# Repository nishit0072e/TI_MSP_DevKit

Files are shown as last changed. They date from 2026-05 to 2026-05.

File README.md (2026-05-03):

### 3D View
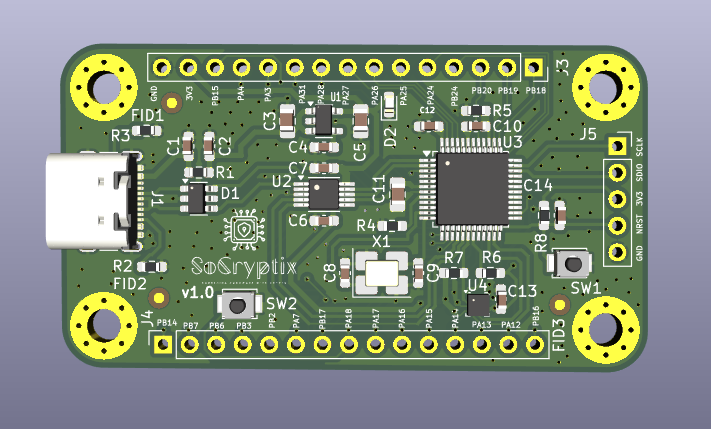
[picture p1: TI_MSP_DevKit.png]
3D View

### Schematic View
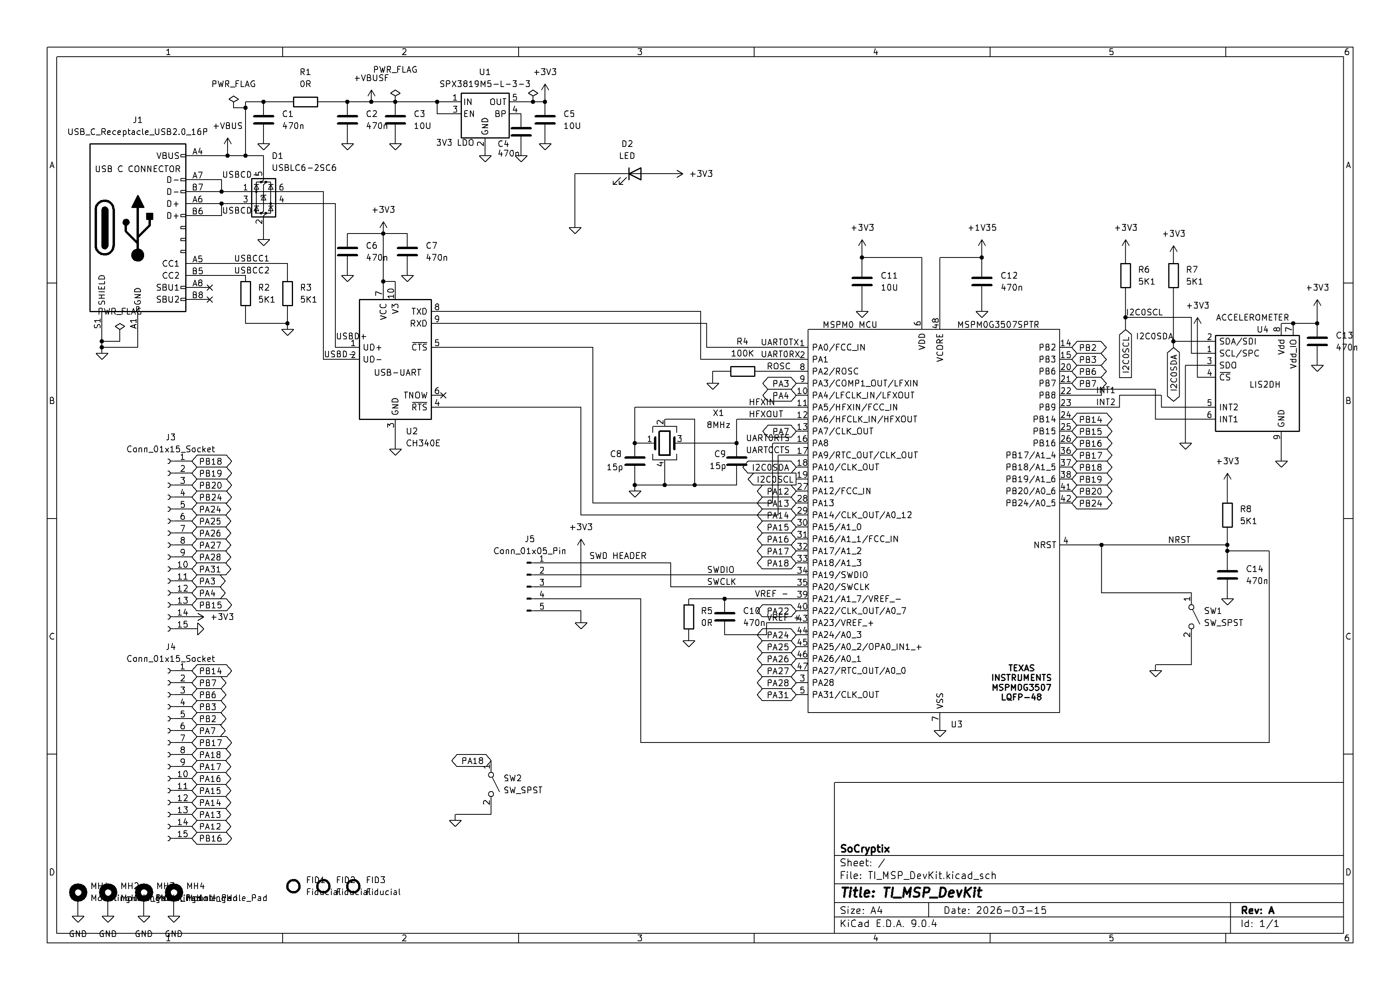
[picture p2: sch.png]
Schematic

### Front Copper
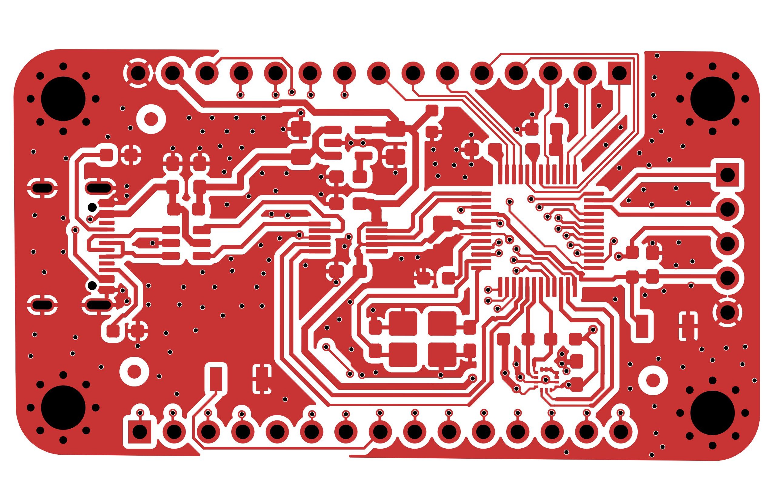
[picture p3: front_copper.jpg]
Front_copper

### Rear Copper
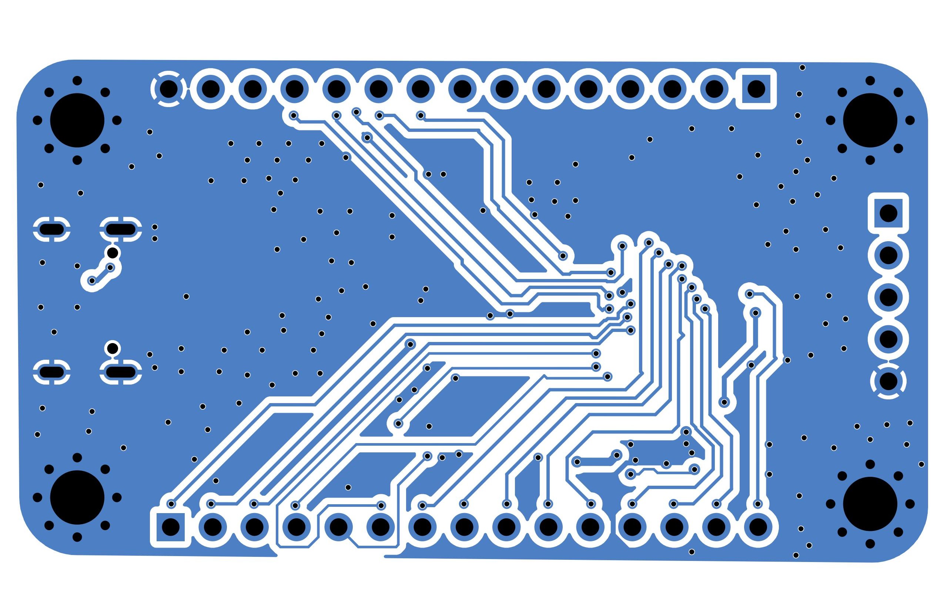
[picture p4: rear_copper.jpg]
Read_copper

### SilkScreen
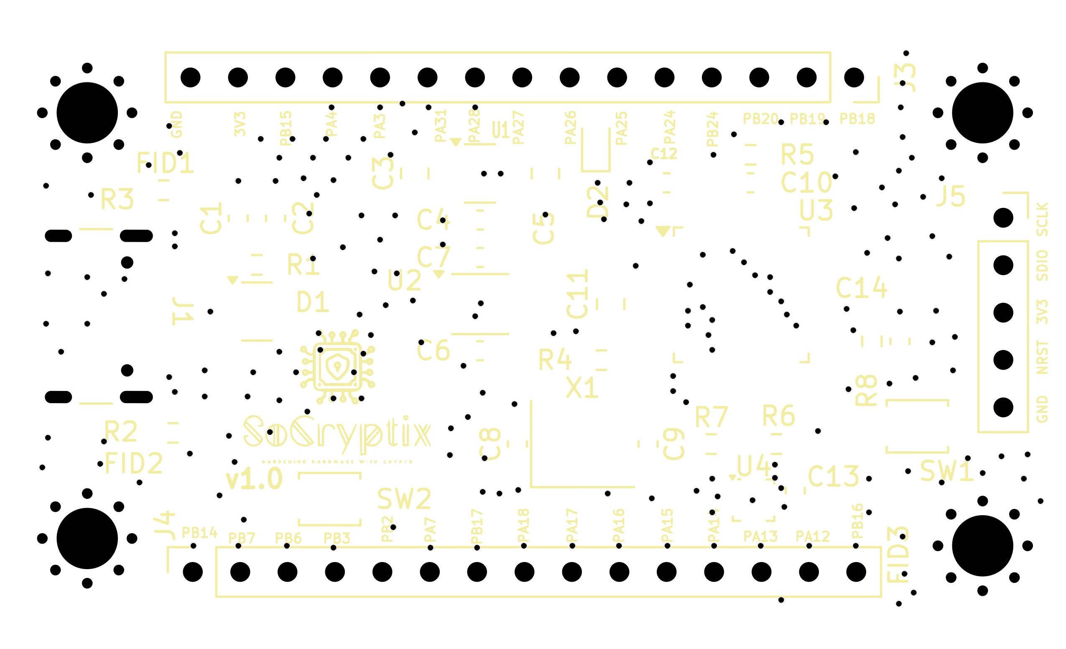
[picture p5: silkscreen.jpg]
Silkscreen

### Solder Mask
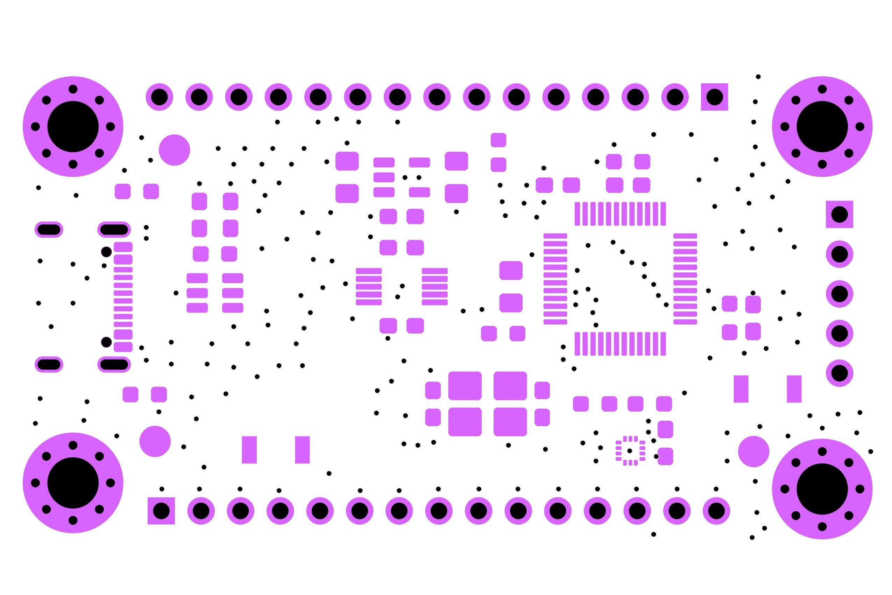
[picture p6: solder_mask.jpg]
Solder_Mask


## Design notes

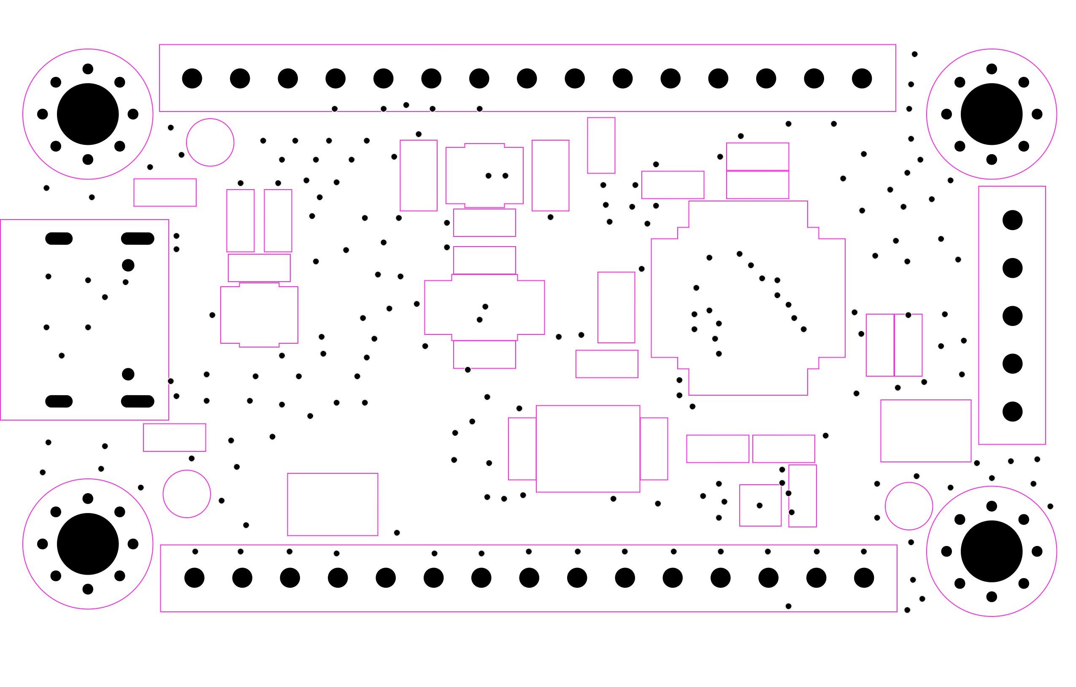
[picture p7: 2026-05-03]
front_courtyard.jpg

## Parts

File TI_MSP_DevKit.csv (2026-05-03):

Reference | Qty | Value | DNP | Exclude from BOM | Exclude from Board | Footprint | Datasheet | LCSC
C1,C2,C4,C6,C7,C10,C12,C13,C14 | 9 | 470n |  |  |  | Capacitor_SMD:C_0603_1608Metric_Pad1.08x0.95mm_HandSolder | ~ | C13967
C3,C5,C11 | 3 | 10U |  |  |  | Capacitor_SMD:C_0805_2012Metric_Pad1.18x1.45mm_HandSolder | ~ | C15850
C8,C9 | 2 | 15p |  |  |  | Capacitor_SMD:C_0603_1608Metric_Pad1.08x0.95mm_HandSolder | ~ | C2594277
D1 | 1 | USBLC6-2SC6 |  |  |  | Package_TO_SOT_SMD:SOT-23-6 | https://www.st.com/resource/en/datasheet/usblc6-2.pdf | C2827654
D2 | 1 | LED |  |  |  | LED_SMD:LED_0603_1608Metric | ~ | C19171390
FID1,FID2,FID3 | 3 | Fiducial |  | Excluded from BOM |  | Fiducial:Fiducial_1mm_Mask2mm | ~
J1 | 1 | USB_C_Receptacle_USB2.0_16P |  |  |  | Connector_USB:USB_C_Receptacle_GCT_USB4105-xx-A_16P_TopMnt_Horizontal | https://www.usb.org/sites/default/files/documents/usb_type-c.zip | C2765186
J3,J4 | 2 | Conn_01x15_Socket |  |  |  | Connector_PinSocket_2.54mm:PinSocket_1x15_P2.54mm_Vertical | ~ | C7499333
J5 | 1 | Conn_01x05_Pin |  |  |  | Connector_PinSocket_2.54mm:PinSocket_1x05_P2.54mm_Vertical | ~ | C42431835
MH1,MH2,MH3,MH4 | 4 | MountingHole_Pad |  | Excluded from BOM |  | MountingHole:MountingHole_3.2mm_M3_Pad_Via | ~
R1,R5 | 2 | 0R |  |  |  | Resistor_SMD:R_0603_1608Metric_Pad0.98x0.95mm_HandSolder | ~ | C95177
R2,R3,R6,R7,R8 | 5 | 5K1 |  |  |  | Resistor_SMD:R_0603_1608Metric_Pad0.98x0.95mm_HandSolder | ~ | C2907044
R4 | 1 | 100K |  |  |  | Resistor_SMD:R_0603_1608Metric_Pad0.98x0.95mm_HandSolder | ~ | C122538
SW1,SW2 | 2 | SW_SPST |  |  |  | Button_Switch_SMD:SW_SPST_B3U-1000P | ~ | C720477
U1 | 1 | SPX3819M5-L-3-3 |  |  |  | Package_TO_SOT_SMD:SOT-23-5 | https://www.exar.com/content/document.ashx?id=22106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 | C9055
U2 | 1 | CH340E |  |  |  | Package_SO:MSOP-10_3x3mm_P0.5mm | https://www.mpja.com/download/35227cpdata.pdf | C99652
U3 | 1 | MSPM0G3507SPTR |  |  |  | Package_QFP:LQFP-48_7x7mm_P0.5mm | https://www.ti.com/lit/ds/symlink/mspm0g3507.pdf?ts=1773558363695 | C22362630
U4 | 1 | LIS2DH |  |  |  | Package_LGA:LGA-14_2x2mm_P0.35mm_LayoutBorder3x4y | http://www.st.com/web/en/resource/technical/document/datasheet/DM00042751.pdf | C110926
X1 | 1 | 8MHz |  |  |  | Crystal:Crystal_SMD_3225-4Pin_3.2x2.5mm_HandSoldering | ~ | C390495

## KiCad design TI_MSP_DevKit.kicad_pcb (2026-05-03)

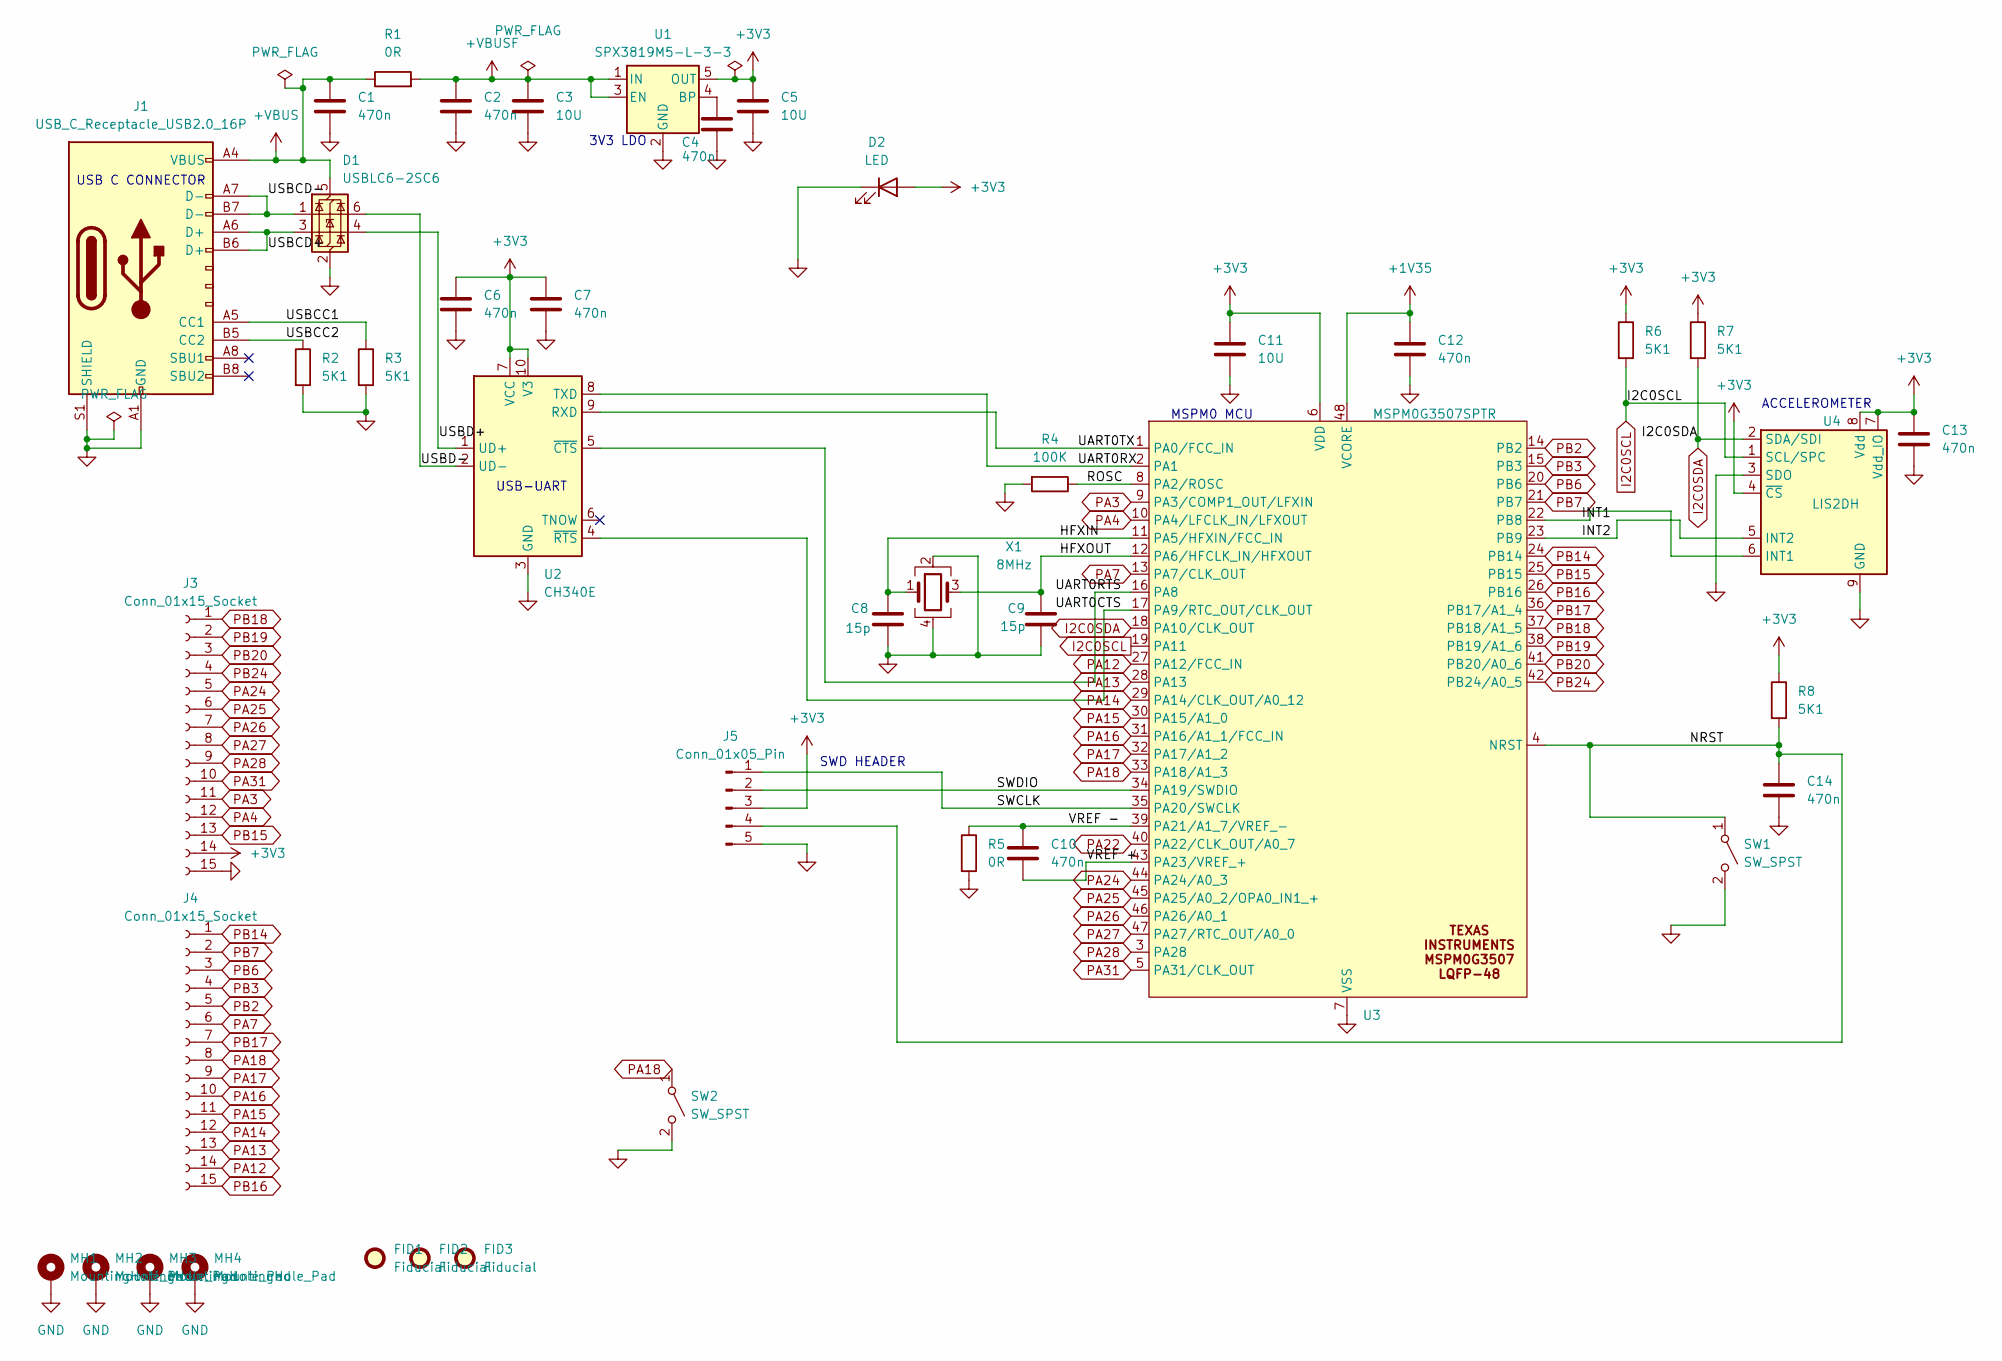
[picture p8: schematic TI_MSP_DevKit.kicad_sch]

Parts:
C1, C2, C4, C6, C7, C10, C12, C13, C14: 470n; C_0603_1608Metric_Pad1.08x0.95mm_HandSolder; Part Number CL21B474KBFNNNE; LCSC C13967
C3, C5, C11: 10U; C_0805_2012Metric_Pad1.18x1.45mm_HandSolder; Part Number CL21A106KAYNNNE; LCSC C15850
C8, C9: 15p; C_0603_1608Metric_Pad1.08x0.95mm_HandSolder; Part Number CL21B474KBFNNNE; LCSC C2594277
D1: USBLC6-2SC6; SOT-23-6; LCSC C2827654
D2: LED; LED_0603_1608Metric; LCSC C19171390
FID1, FID2, FID3: Fiducial; Fiducial_1mm_Mask2mm
J1: USB_C_Receptacle_USB2.0_16P; USB_C_Receptacle_GCT_USB4105-xx-A_16P_TopMnt_Horizontal; LCSC C2765186
J3, J4: Conn_01x15_Socket; PinSocket_1x15_P2.54mm_Vertical; LCSC C7499333
J5: Conn_01x05_Pin; PinSocket_1x05_P2.54mm_Vertical; LCSC C42431835
MH1, MH2, MH3, MH4: MountingHole_Pad; MountingHole_3.2mm_M3_Pad_Via
R1, R5: 0R; R_0603_1608Metric_Pad0.98x0.95mm_HandSolder; LCSC C95177
R2, R3, R6, R7, R8: 5K1; R_0603_1608Metric_Pad0.98x0.95mm_HandSolder; LCSC C2907044
R4: 100K; R_0603_1608Metric_Pad0.98x0.95mm_HandSolder; Part Number RT0603BRD07100KL; LCSC C122538
SW1, SW2: SW_SPST; SW_SPST_B3U-1000P; LCSC C720477
U1: SPX3819M5-L-3-3; SOT-23-5; LCSC C9055
U2: CH340E; MSOP-10_3x3mm_P0.5mm; LCSC C99652
U3: MSPM0G3507SPTR; LQFP-48_7x7mm_P0.5mm; Manufacturer Part Number MSPM0G3507SPTR; LCSC C22362630
U4: LIS2DH; LGA-14_2x2mm_P0.35mm_LayoutBorder3x4y; LCSC C110926
X1: 8MHz; Crystal_SMD_3225-4Pin_3.2x2.5mm_HandSoldering; LCSC C390495

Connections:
+1V35: C12.1, U3.48 (VCORE)
+3V3: C5.1, C6.1, C7.1, C11.1, C13.1, D2.2 (A), J3.14, J5.3, R6.1, R7.1, R8.1, U1.5 (OUT), U2.7 (VCC), U2.10 (V3), U3.6 (VDD), U4.4 (~CS), U4.7 (Vdd_IO), U4.8 (Vdd)
+VBUS: C1.1, D1.5 (VBUS), J1.A4 (VBUS), J1.A9 (VBUS), J1.B4 (VBUS), J1.B9 (VBUS), R1.1
+VBUSF: C2.1, C3.1, R1.2, U1.1 (IN), U1.3 (EN)
/HFXIN: C8.1, U3.11 (PA5/HFXIN/FCC_IN), X1.1
/HFXOUT: C9.1, U3.12 (PA6/HFCLK_IN/HFXOUT), X1.3
/INT1: U3.22 (PB8), U4.6 (INT1)
/INT2: U3.23 (PB9), U4.5 (INT2)
/NRST: C14.1, J5.4, R8.2, SW1.1 (A), U3.4 (NRST)
/ROSC: R4.1, U3.8 (PA2/ROSC)
/SWCLK: J5.1, U3.35 (PA20/SWCLK)
/SWDIO: J5.2, U3.34 (PA19/SWDIO)
/UART0CTS: U2.4 (~RTS), U3.17 (PA9/RTC_OUT/CLK_OUT)
/UART0RTS: U2.5 (~CTS), U3.16 (PA8)
/UART0RX: U2.8 (TXD), U3.2 (PA1)
/UART0TX: U2.9 (RXD), U3.1 (PA0/FCC_IN)
/USBCC1: J1.A5 (CC1), R3.1
/USBCC2: J1.B5 (CC2), R2.1
/USBCD+: D1.3 (I/O2), J1.A6 (D+), J1.B6 (D+)
/USBCD-: D1.1 (I/O1), J1.A7 (D-), J1.B7 (D-)
/USBD+: D1.4 (I/O2), U2.1 (UD+)
/USBD-: D1.6 (I/O1), U2.2 (UD-)
/VREF +: C10.2, U3.43 (PA23/VREF_+)
/VREF -: C10.1, R5.1, U3.39 (PA21/A1_7/VREF_-)
GND: C1.2, C2.2, C3.2, C4.2, C5.2, C6.2, C7.2, C8.2, C9.2, C11.2, C12.2, C13.2, C14.2, D1.2 (GND), D2.1 (K), J1.A1 (GND), J1.A12 (GND), J1.B1 (GND), J1.B12 (GND), J1.S1 (SHIELD), J3.15, J5.5, MH1.1, MH2.1, MH3.1, MH4.1, R2.2, R3.2, R4.2, R5.2, SW1.2 (B), SW2.2 (B), U1.2 (GND), U2.3 (GND), U3.7 (VSS), U4.3 (SDO), U4.9 (GND), X1.2, X1.4
I2C0SCL: R6.2, U3.19 (PA11), U4.1 (SCL/SPC)
I2C0SDA: R7.2, U3.18 (PA10/CLK_OUT), U4.2 (SDA/SDI)
unnamed: C4.1, U1.4 (BP)
unnamed: U4.10 (GND), U4.11 (GND), U4.12 (GND), U4.13 (GND), U4.14 (GND)
PA3: J3.11, U3.9 (PA3/COMP1_OUT/LFXIN)
PA4: J3.12, U3.10 (PA4/LFCLK_IN/LFXOUT)
PA7: J4.6, U3.13 (PA7/CLK_OUT)
PA12: J4.14, U3.27 (PA12/FCC_IN)
PA13: J4.13, U3.28 (PA13)
PA14: J4.12, U3.29 (PA14/CLK_OUT/A0_12)
PA15: J4.11, U3.30 (PA15/A1_0)
PA16: J4.10, U3.31 (PA16/A1_1/FCC_IN)
PA17: J4.9, U3.32 (PA17/A1_2)
PA18: J4.8, SW2.1 (A), U3.33 (PA18/A1_3)
PA22: U3.40 (PA22/CLK_OUT/A0_7)
PA24: J3.5, U3.44 (PA24/A0_3)
PA25: J3.6, U3.45 (PA25/A0_2/OPA0_IN1_+)
PA26: J3.7, U3.46 (PA26/A0_1)
PA27: J3.8, U3.47 (PA27/RTC_OUT/A0_0)
PA28: J3.9, U3.3 (PA28)
PA31: J3.10, U3.5 (PA31/CLK_OUT)
PB2: J4.5, U3.14 (PB2)
PB3: J4.4, U3.15 (PB3)
PB6: J4.3, U3.20 (PB6)
PB7: J4.2, U3.21 (PB7)
PB14: J4.1, U3.24 (PB14)
PB15: J3.13, U3.25 (PB15)
PB16: J4.15, U3.26 (PB16)
PB17: J4.7, U3.36 (PB17/A1_4)
PB18: J3.1, U3.37 (PB18/A1_5)
PB19: J3.2, U3.38 (PB19/A1_6)
PB20: J3.3, U3.41 (PB20/A0_6)
PB24: J3.4, U3.42 (PB24/A0_5)

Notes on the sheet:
MSPM0 MCU
ACCELEROMETER
USB-UART
SWD HEADER
USB C CONNECTOR
3V3 LDO

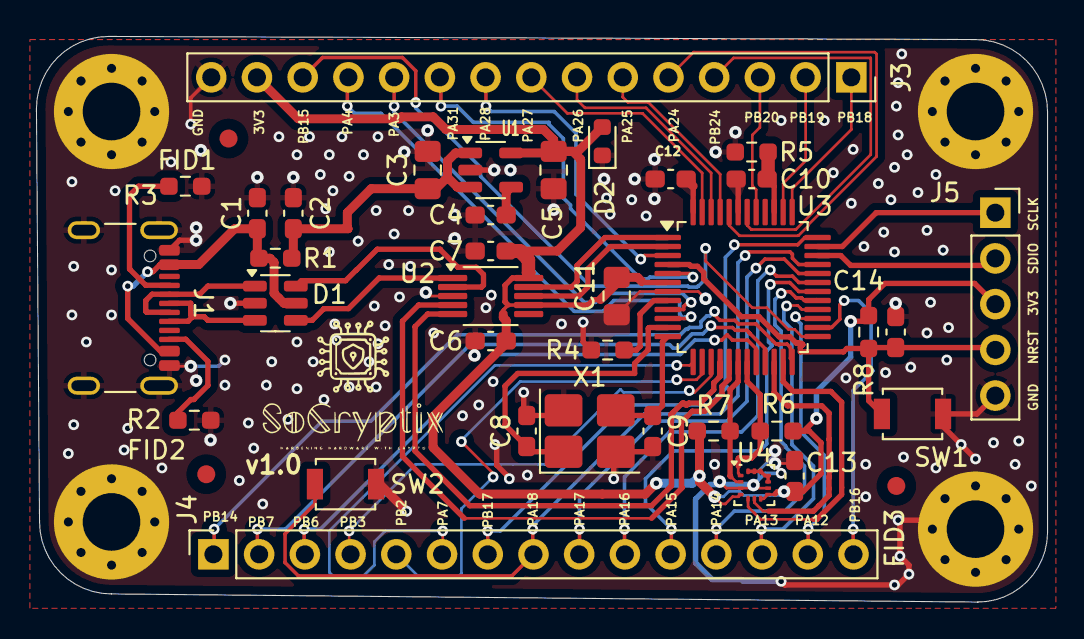
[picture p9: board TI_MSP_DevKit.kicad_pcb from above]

Board: 2 copper layers, 56.2 x 31.4 mm, 42 parts (0 on the bottom side), 57 nets.
